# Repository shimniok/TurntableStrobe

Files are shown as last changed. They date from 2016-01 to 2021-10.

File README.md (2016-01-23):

# TurntableStrobe

Check your turntable's speed with TurntableStrobe, a highly accurate, tiny, low-cost, handheld turntable strobe. Or retrofit your turntable with the permanent-mount version.

With a crystal rated ±0.003% accuracy at 25°C, it is far more accurate than a mains frequency strobe on most turntables.

For sale on [Tindie](https://www.tindie.com/products/bot_thoughts/pocket-turntable-strobe/)

[Documentation](https://github.com/shimniok/TurntableStrobe/tree/master/documentation/)

## Features

* Crystal rated at ±0.003% accuracy at 25°C
* Use these free strobe discs: 60HzStrobeDisc.pdf or 50HzStrobeDisc.pdf
* Tiny CR1225 battery, included
* 1" long (not including the LED) x 3/4" wide
* Tactile on switch
* Handheld or Permanent mount

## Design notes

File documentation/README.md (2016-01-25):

# TurntableStrobe User Manual
Use TurntableStrobe, a highly accurate, tiny, hand held LED strobe, to check the pitch calibration of your turntable.

## Why Calibrate?
To ensure your records play back at the correct pitch (speed), you need to calibrate your deck using a turntable strobe. For the highest accuracy, TurntableStrobe uses a quartz crystal rated ±0.003% accuracy at 25°C, more than accurate enough to ensure a precise calibration.

Though many turntables have built-in strobes, they run off of the mains frequency which [varies over time](http://dabbledoo.weebly.com/mains-frequency.html). And, many turntables have no strobe. In either case, TurntableStrobe provides a quick and easy, but highly accurate, calibration reference at low cost.

## Getting Started
* Remove TurntableStrobe and the CR1225 battery from the anti-static bag
* Remove the CR1225 battery from its bubble
* Match the ```+``` symbol on the battery and battery holder
* Insert the battery with the ```+``` symbols facing up.
* Just press the button on top to activate the strobe.

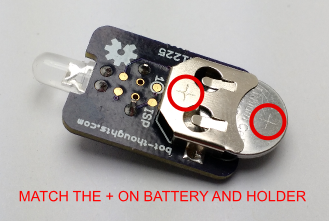
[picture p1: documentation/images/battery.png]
battery


## How to Calibrate Your Turntable
If your turntable's platter has timing marks (pictured below) skip to *Checking Calibration*. Otherwise, you can print a strobe disc as explained below.

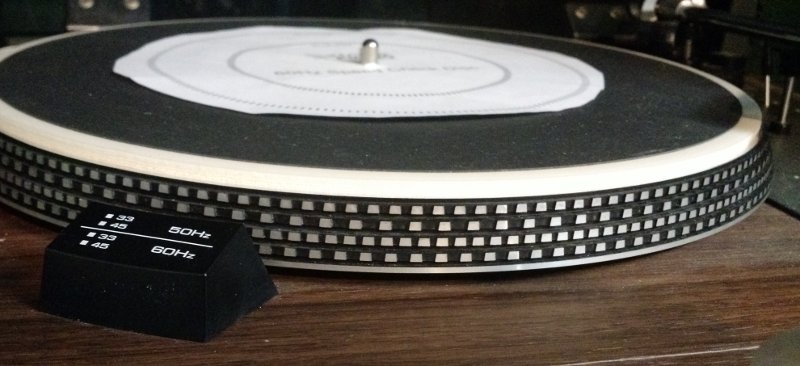
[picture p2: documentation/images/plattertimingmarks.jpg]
timing marks
  
*My Realistic Lab-400 has 50Hz and 60Hz timing marks. Strobe disc also pictured.*

1. Download one of these free turntable strobe discs on your printer:
  * [60Hz.pdf](http://www.extremephono.com/ftp/60Hz.PDF) for 60Hz TurntableStrobe
  * [50Hz.pdf](http://www.extremephono.com/ftp/50Hz.PDF) for 50Hz TurntableStrobe
* Cut out the disc and cut out a hole for the turntable spindle.
* Remove any records from the turntable
* Place the strobe disc on the turntable

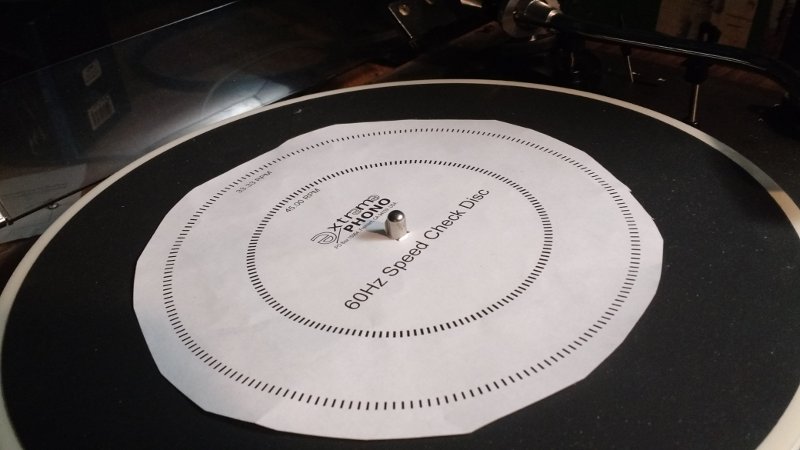
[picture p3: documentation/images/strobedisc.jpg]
strobe disc


### Checking Calibration
1. Start the turntable (refer to your owner's manual if necessary)
* Select the timing marks corresponding to the current turntable speed
* Hold the TurntableStrobe at least 2" (5cm) away from the timing marks (on the platter or strobe disc, as applicable)
* Press the TurntableStrobe button to activate the light
* The timing marks should now appear distinct though possibly a little bit blurry
* If the marks appear to be moving slowly, then the speed/pitch calibration is incorrect

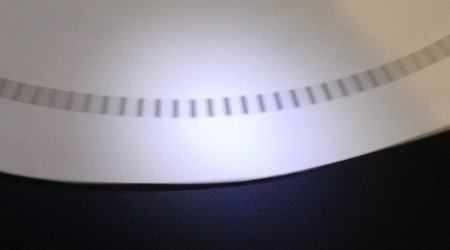
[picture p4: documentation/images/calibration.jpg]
calibration
  
*Calibration using a strobe disc*

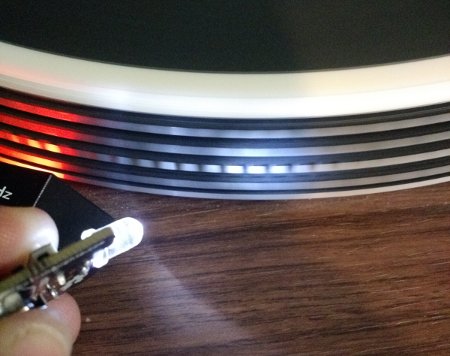
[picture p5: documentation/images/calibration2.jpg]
calibration2
  
*Calibration using platter timing marks*

If your turntable has an external pitch or speed adjustment knob, you can now adjust the speed of your deck.

### Adjusting Pitch
Some turntables have separate speed / pitch knobs for 45 rpm and 33-1/3 rpm, while others only have a single pitch knob.

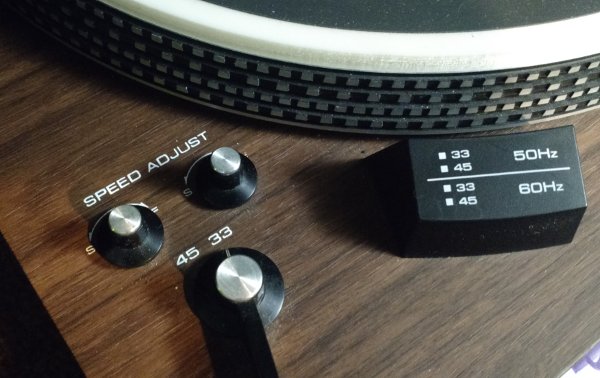
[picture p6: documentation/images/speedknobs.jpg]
LAB-400 pitch
  
*My LAB-400 has independent adjustments for 45 RPM and 33-1/3 RPM.*

1. Find the pitch knob corresponding to the current speed of the turntable.
* Adjust the pitch knob very slowly until the timing marks appear to be stationary
* You may find the marks will slowly oscillate forward and backward.
  * This variation in pitch is normal and is called *wow*.
  * Typically, better turntables have lower variation in pitch.
* To calibrate for an *average* speed, ensure the timing marks appear to move forward and backward by the same amount; that is, they remain stationary *on average*.
* It may not be possible to get it perfect. Just do your best.

## Troubleshooting

### Timing marks are an indistinct blur

| Cause | Solution |
| ----- | --- |
| Mismatch between timing marks and strobe | Make sure the platter timing marks (or strobe disc) match the frequency of your turntable strobe. |
| 45 RPM speed selected but 33-1/3 timing marks are illuminated, or vice versa | Strobe discs and turntable platters use two sets of timing marks, one for each speed. Illuminate the marks corresponding to the speed selection of your turntable. |
| Problem with turntable speed | You could try replacing the belt (if applicable), or have the turntable checked and serviced if necessary. There could be a problem with the motor, the speed controller, or something else I haven't thought of. |

### Timing difficult to make perfectly stationary

| Cause | Solution |
| ----- | --- |
| Speed/Pitch potentiometer is dirty | Clean potentiometer with Deoxit and lubricate with FaderLube or equivalent |
| Turntable wow | Lower end turntables may have a fair bit of wow. As long as you can't hear pitch variation when playing back long, sustained notes, you can ignore the wow and do your best to adjust pitch. If wow sounds excessive, you can try cleaning and lubricating the pitch potenitometer as above, replacing the belt if applicable, and/or having the turntable checked and serviced. |

### Strobe light is very dim or strobe does not light up at all

| Cause | Solution |
| ----- | --- |
| Battery is low | Change battery |

If you are still having problems, please [contact me on Tindie](https://www.tindie.com/stores/bot_thoughts/) and I'll do my best to help you out.

## Accuracy
The quartz crystals selected for use on the Turntable strobe modules have a frequency tolerance of ±30 ppm at 25 ºC (±0.003%). Temperature stability is ±30 ppm over (-20ºC - +70ºC) but of course we can expect a much narrower tolerance for normal indoor temperatures.

I measure the frequency of every single TurntableStrobe before selling it. So far. frequencies range between -0.0015% to -0.0035% of the target frequency. Testing is conducted in my basement at around 20-25°C using a Saleae Logic analyzer with 42ns accuracy.

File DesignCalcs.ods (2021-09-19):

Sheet: OperArea
Safe operating area (voltage vs frequency) |  |  |  |  | CR1225 Discharge Curves
ATtiny25SSU from datasheet
 |  |  | Linear interpolation
MHz | Max Voltage |  | m | b
10 | 2.7 | See Note | 0.18 | 0.9
11 | 2.88
12 | 3.06 | See Note
13 | 3.24
14 | 3.42
15 | 3.6
16 | 3.78
17 | 3.96
18 | 4.14
19 | 4.32
20 | 4.5
 | Note: the turntable strobe runs off a “3V” CR1225, with discharge curve running down to around 2.5V at end of life. Safe operating area for ATtiny25SSU is only 2.7V minimum. ATtiny25V can run down to 1.8V. However, expected use of the strobe will be on the order of minutes per year, so with even a 100 hour life, the battery should last for years. However, running the board at full 12MHz means potential problems in a shorter timespan, unfortunately. :( By running it at DIV8 clock, hopefully that resolves the problem.
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

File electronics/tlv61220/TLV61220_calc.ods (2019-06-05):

VFB | 0.5
R1 | 1.00E+06
R2 | 1.50E+05
VOUT | VR2 (kohm)
2.5 | 250,000 | 100000
2.7 | 227,273
2.8 | 217,391
2.9 | 208,333
3.0 | 200,000
3.1 | 192,308
3.2 | 185,185
3.3 | 178,571
3.5 | 166,667 | 16667

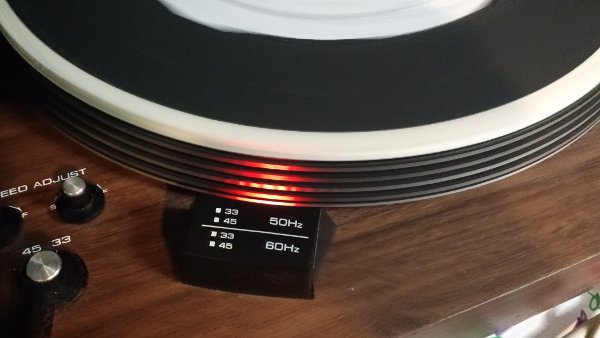
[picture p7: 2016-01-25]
documentation/images/builtinstrobe.jpg

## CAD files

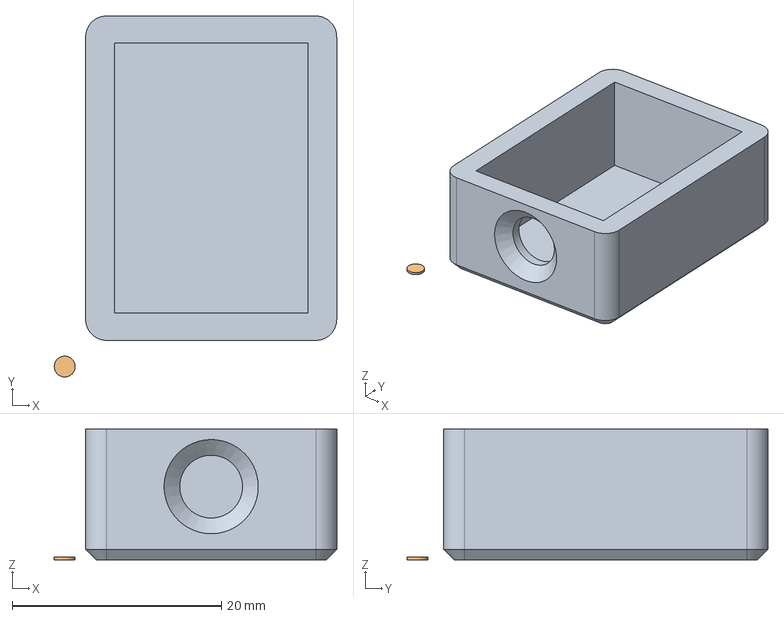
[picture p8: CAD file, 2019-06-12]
enclosure/ttstrobe_body.fcstd
27.0 x 34.5 x 12.5 mm

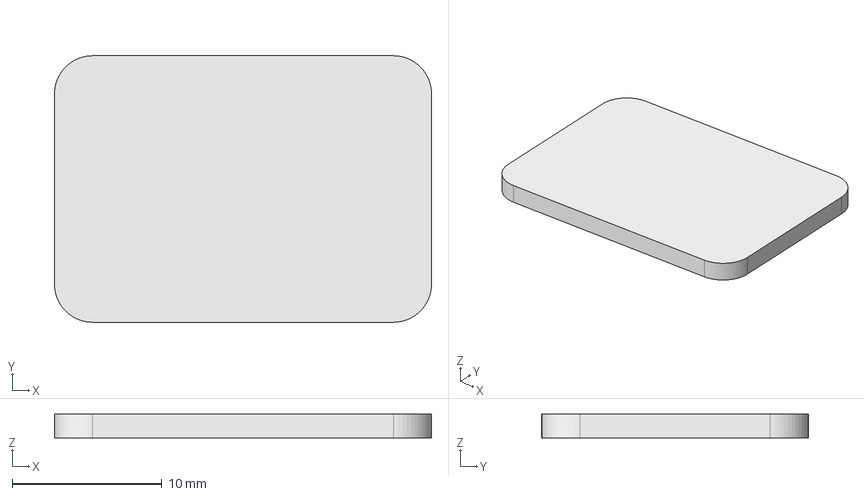
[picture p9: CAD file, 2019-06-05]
TTStrobe.fcstd
25.1 x 17.8 x 1.60 mm

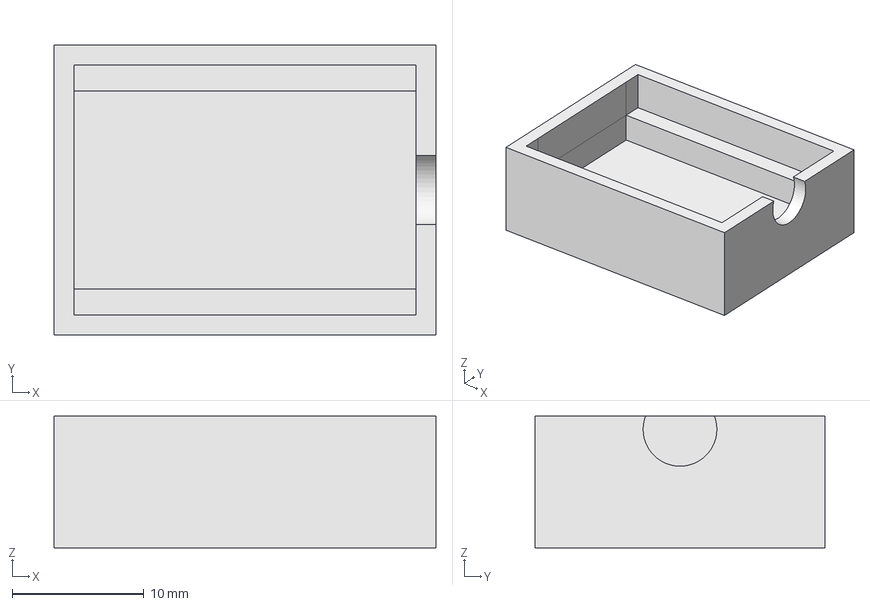
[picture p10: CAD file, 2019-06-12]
enclosure/ttstrobe.fcstd
29.0 x 22.0 x 10.0 mm

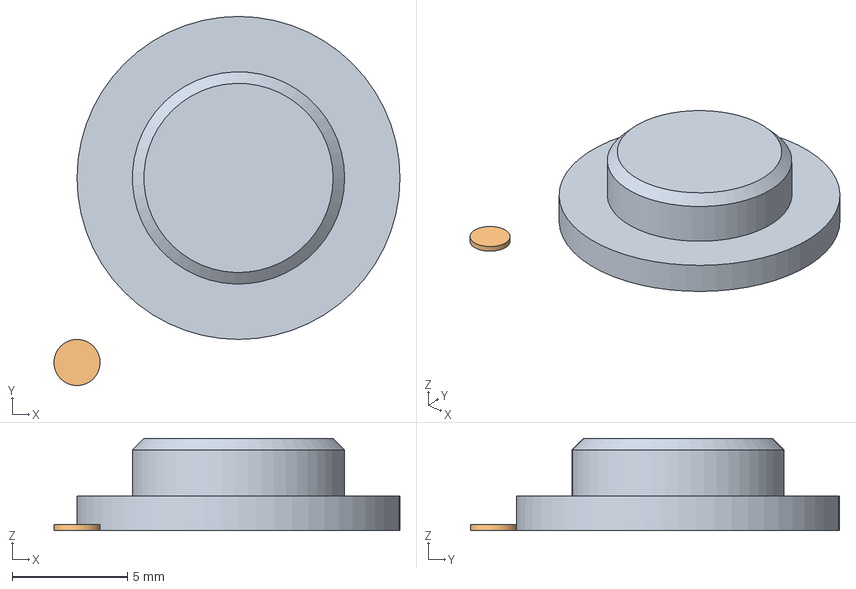
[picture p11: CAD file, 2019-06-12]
enclosure/ttstrobe_button.fcstd
15.0 x 16.0 x 4.00 mm

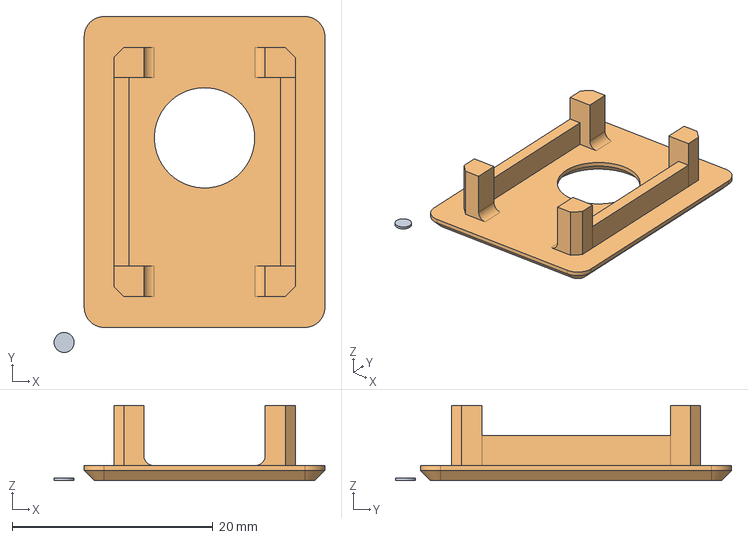
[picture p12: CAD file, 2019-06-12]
enclosure/ttstrobe_top.fcstd
27.0 x 33.5 x 7.50 mm

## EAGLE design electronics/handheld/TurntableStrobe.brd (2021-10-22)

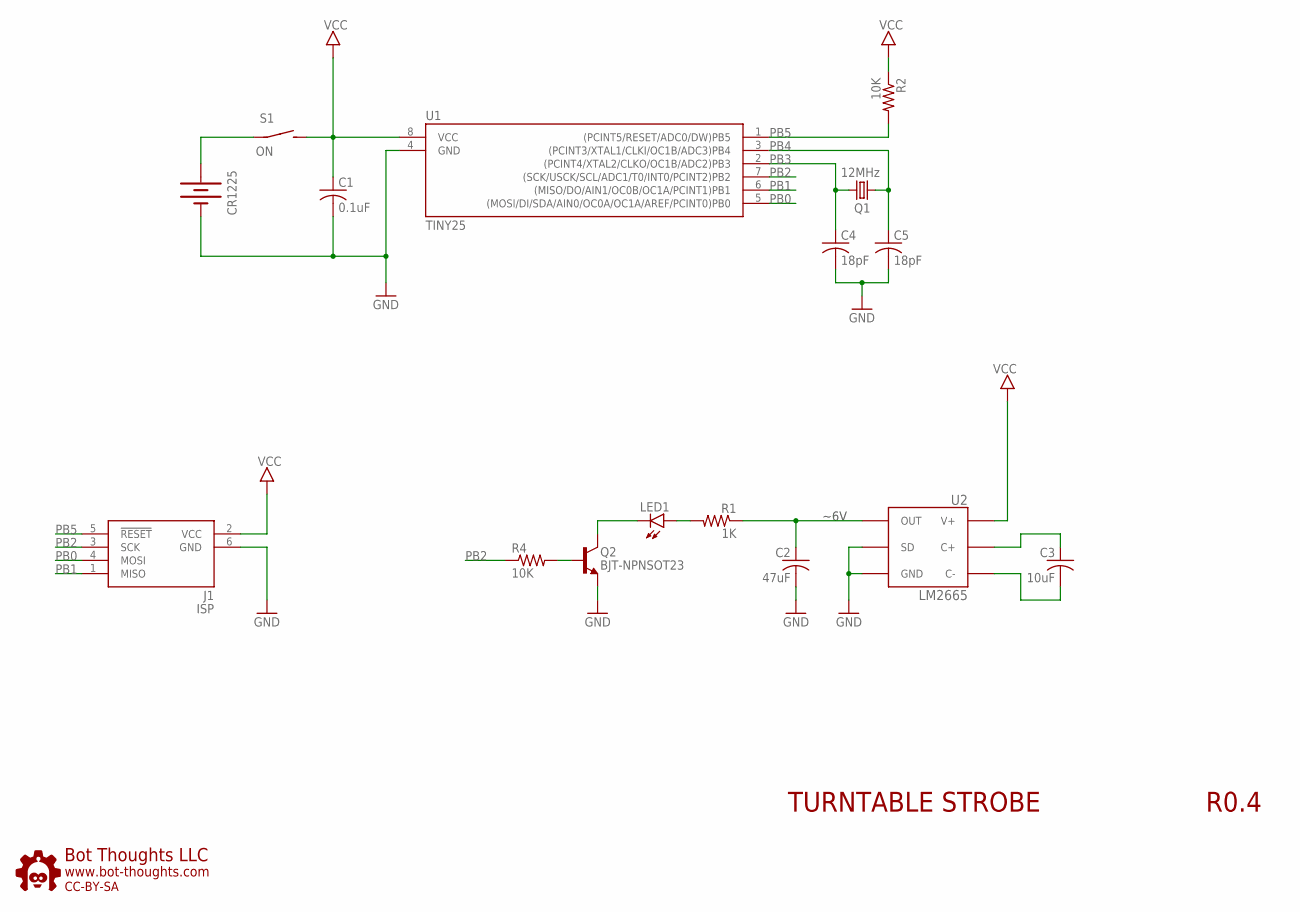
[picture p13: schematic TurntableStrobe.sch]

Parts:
C1: 0.1uF; C0603
C2: 47uF; C0603
C3: 10uF; C0603
C4, C5: 18pF; C0603
CR1225: BATTERY12PTH; BATTCON_12MM_PTH
J1: ISP; 2X3_TP
LED1: LED5MMRA
Q1: 12MHz; NDK_2PAD_5X3
Q2: BJT-NPNSOT23; SOT-23
R1: 1K; R0603
R2, R4: 10K; R0603
S1: ON; 6MMTACTILE_RECT
U1: TINY25; SOIC8N
U2: LM2665; SOT23-6
U$5: BTLOGO-LOGO-SM; BTLOGOS

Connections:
GND: C1.2, C2.2, C4.2, C5.2, CR1225.GND (-), J1.6 (GND), Q2.2 (E), U1.4 (GND), U2.2 (GND), U2.4 (SD)
unnamed: Q2.3 (B), R4.2
unnamed: C3.1, U2.6 (C+)
unnamed: LED1.A, R1.2
unnamed: C3.2, U2.3 (C-)
unnamed: LED1.C, Q2.1 (C)
PB0: J1.4 (MOSI), U1.5 ((MOSI/DI/SDA/AIN0/OC0A/OC1A/AREF/PCINT0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)
PB1: J1.1 (MISO), U1.6 ((MISO/DO/AIN1/OC0B/OC1A/PCINT1)PB1)
PB2: J1.3 (SCK), R4.1, U1.7 ((SCK/USCK/SCL/ADC1/T0/INT0/PCINT2)PB2)
PB3: C4.1, Q1.P$2 (2), U1.2 ((PCINT4/XTAL2/CLKO/OC1B/ADC2)PB3)
PB4: C5.1, Q1.P$1 (1), U1.3 ((PCINT3/XTAL1/CLKI/OC1B/ADC3)PB4)
PB5: J1.5 (!RESET), R2.2, U1.1 ((PCINT5/RESET/ADC0/DW)PB5)
VBAT: CR1225.VCC@1 (+), S1.P$1
VCC: C1.1, J1.2 (VCC), R2.1, S1.P$2 (S), U1.8 (VCC), U2.1 (V+)
VHI: C2.1, R1.1, U2.5 (OUT)

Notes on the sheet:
~6V
TURNTABLE STROBE
R0.4

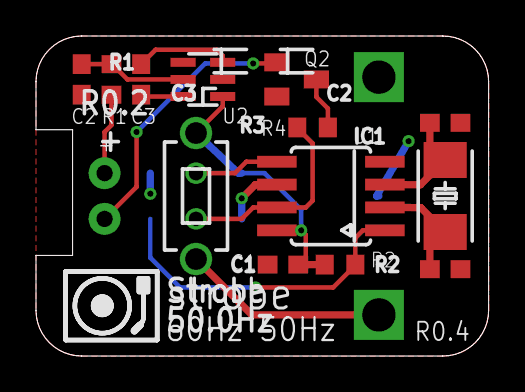
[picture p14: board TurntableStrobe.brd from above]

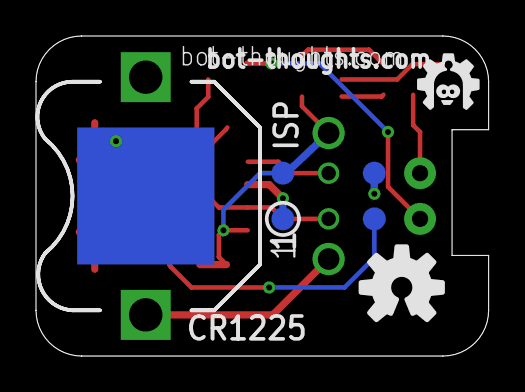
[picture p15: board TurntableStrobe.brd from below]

Board: 2 copper layers, 25.1 x 17.8 mm, 17 parts (3 on the bottom side), 15 nets.

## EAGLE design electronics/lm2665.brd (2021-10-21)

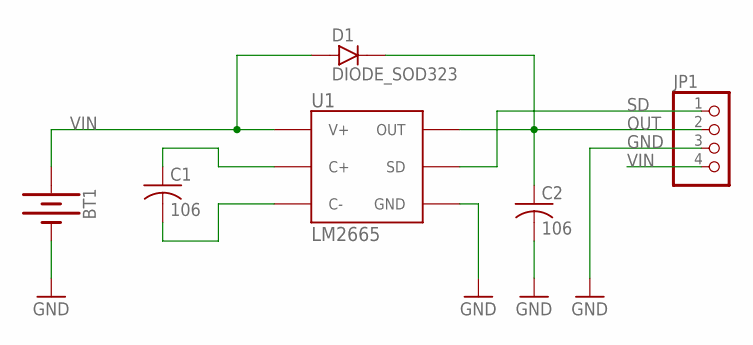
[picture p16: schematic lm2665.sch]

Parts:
BT1: BATTERY-12MM_PTH; BATTCON_12MM_PTH
C1, C2: 106; 1206
D1: DIODE_SOD323; SOD-323
JP1: PINHD-1X04_2.54-S; 1X04-S
U1: LM2665; SOT23-6

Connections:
GND: BT1.GND (-), C2.2 (-), JP1.3, U1.2 (GND)
unnamed: C1.1 (+), U1.6 (C+)
unnamed: C1.2 (-), U1.3 (C-)
OUT: C2.1 (+), D1.C, JP1.2, U1.5 (OUT)
SD: JP1.1, U1.4 (SD)
VIN: BT1.VCC@1 (+), D1.A, JP1.4, U1.1 (V+)

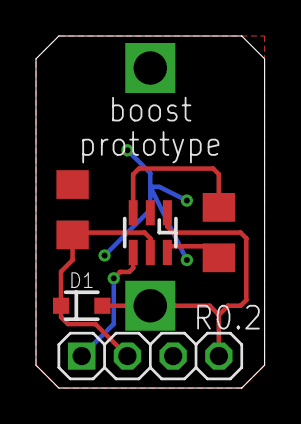
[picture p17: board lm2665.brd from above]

Board: 2 copper layers, 12.7 x 19.6 mm, 6 parts (1 on the bottom side), 6 nets.

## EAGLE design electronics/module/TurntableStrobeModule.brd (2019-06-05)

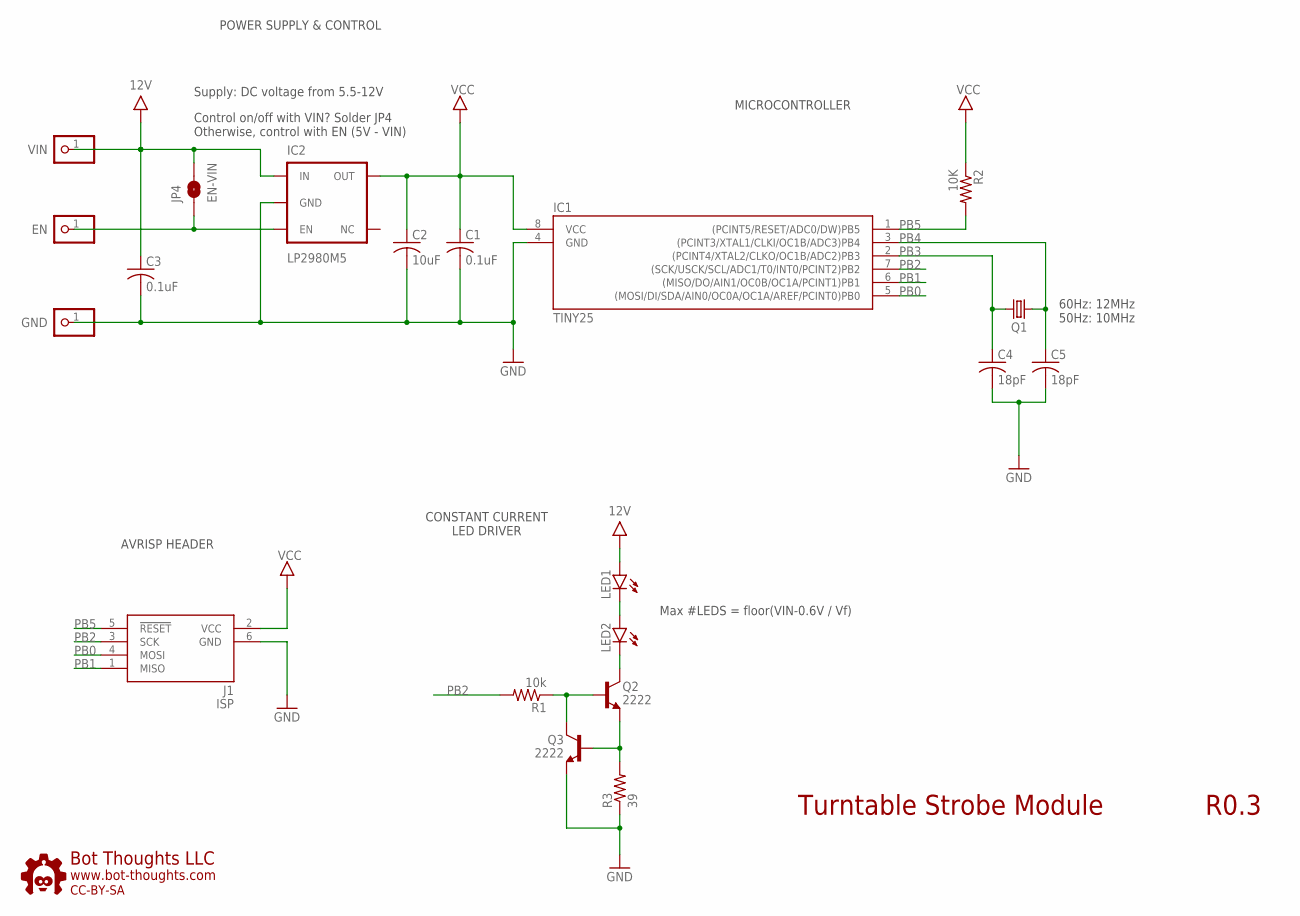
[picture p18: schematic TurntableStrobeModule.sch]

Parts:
C1, C3: 0.1uF; 0603
C2: 10uF; 1206
C4, C5: 18pF; 0603
IC1: TINY25; SOIC8N
IC2: LP2980M5; SOT23-5
J1: ISP; CON6P2R
JP1: EN; 1X01-S
JP2: VIN; 1X01-S
JP3: GND; 1X01-S
JP4: EN-VIN; SMT-JUMPER_2_NO_SILK
LED1, LED2: LED5MMRA
Q1: CRYSTALNDK5X3; NDK_2PAD_5X3
Q2, Q3: 2222; SOT-23
R1: 10k; 0603
R2: 10K; 0603
R3: 39; 0603
U$6: BTLOGO-LOGO-MD; BTLOGOM

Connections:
9V: C3.1 (+), IC2.1 (IN), JP2.1, JP4.2, LED1.A
GND: C1.2 (-), C2.2 (-), C3.2 (-), C4.2 (-), C5.2 (-), IC1.4 (GND), IC2.2 (GND), J1.6 (GND), JP3.1, Q3.2 (E), R3.1
unnamed: Q2.3 (B), Q3.1 (C), R1.1
unnamed: LED1.C, LED2.A
unnamed: LED2.C, Q2.1 (C)
unnamed: Q2.2 (E), Q3.3 (B), R3.2
unnamed: IC2.3 (EN), JP1.1, JP4.1
PB0: IC1.5 ((MOSI/DI/SDA/AIN0/OC0A/OC1A/AREF/PCINT0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), J1.4 (MOSI)
PB1: IC1.6 ((MISO/DO/AIN1/OC0B/OC1A/PCINT1)PB1), J1.1 (MISO)
PB2: IC1.7 ((SCK/USCK/SCL/ADC1/T0/INT0/PCINT2)PB2), J1.3 (SCK), R1.2
PB3: C4.1 (+), IC1.2 ((PCINT4/XTAL2/CLKO/OC1B/ADC2)PB3), Q1.P$2 (2)
PB4: C5.1 (+), IC1.3 ((PCINT3/XTAL1/CLKI/OC1B/ADC3)PB4), Q1.P$1 (1)
PB5: IC1.1 ((PCINT5/RESET/ADC0/DW)PB5), J1.5 (!RESET), R2.2
VCC: C1.1 (+), C2.1 (+), IC1.8 (VCC), IC2.5 (OUT), J1.2 (VCC), R2.1

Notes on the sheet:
Turntable Strobe Module
R0.3
60Hz: 12MHz 50Hz: 10MHz
Control on/off with VIN? Solder JP4 Otherwise, control with EN (5V - VIN)
Supply: DC voltage from 5.5-12V
Max #LEDS = floor(VIN-0.6V / Vf)
CONSTANT CURRENT LED DRIVER
AVRISP HEADER
POWER SUPPLY & CONTROL
MICROCONTROLLER

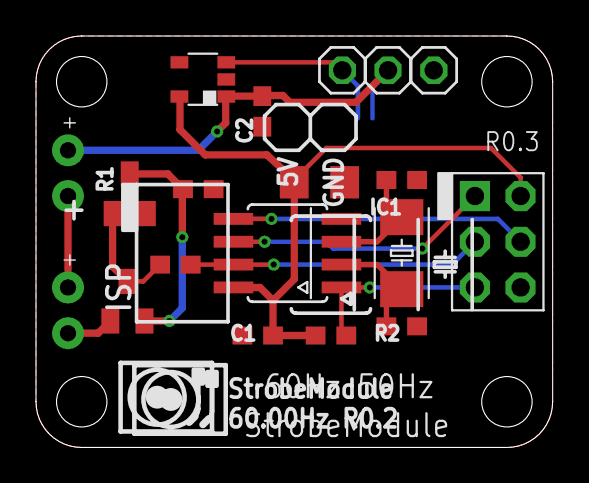
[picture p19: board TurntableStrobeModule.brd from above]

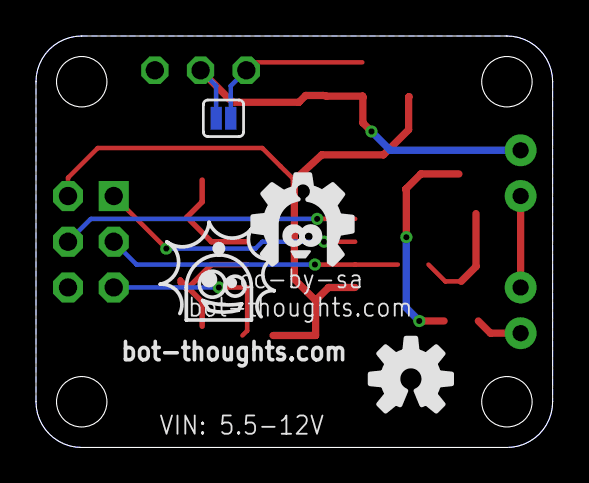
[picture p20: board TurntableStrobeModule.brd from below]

Board: 2 copper layers, 28.7 x 22.9 mm, 21 parts (2 on the bottom side), 14 nets.

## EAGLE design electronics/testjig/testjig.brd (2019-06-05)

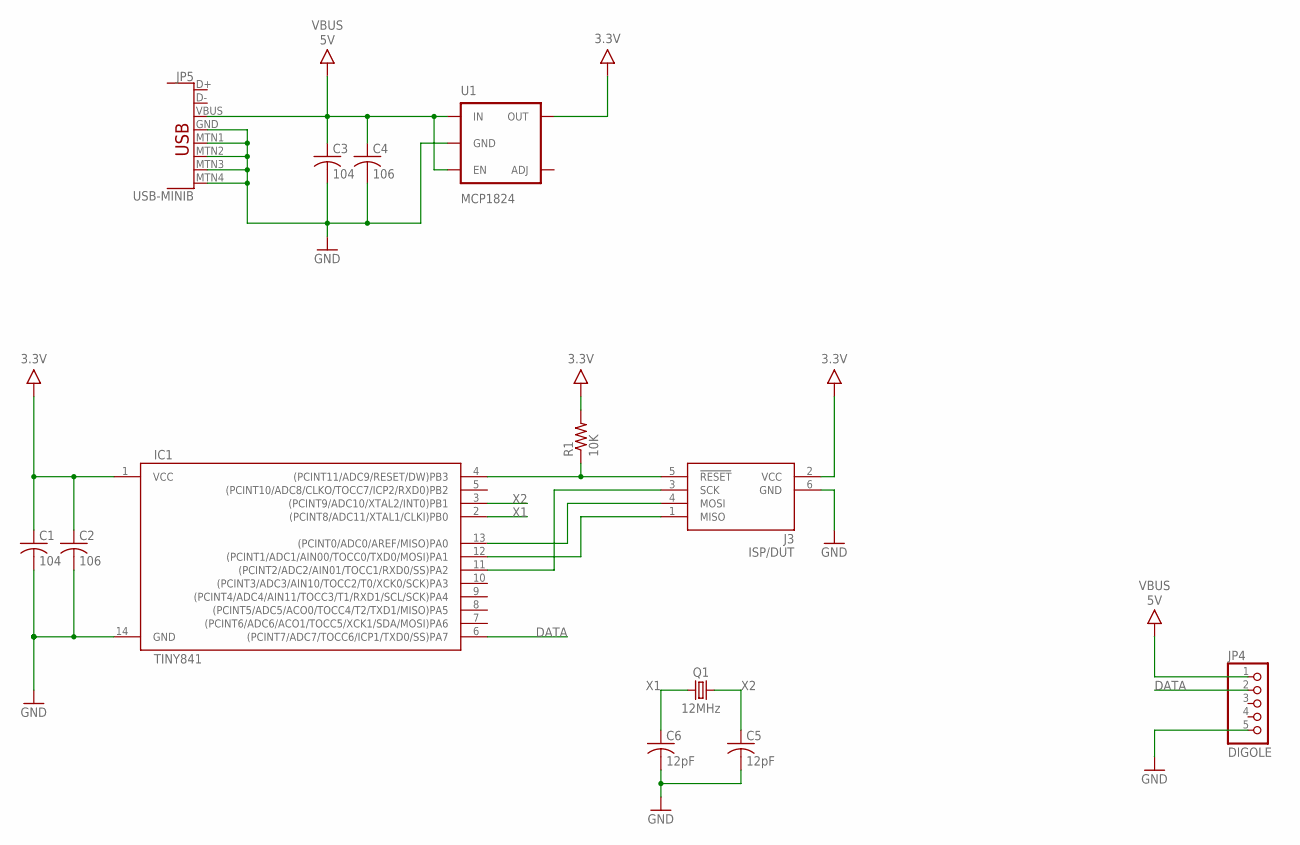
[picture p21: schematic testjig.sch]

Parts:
C1, C3: 104; 0603
C2, C4: 106; 0603
C5, C6: 12pF; 0603
IC1: TINY841; SOIC14N
J3: ISP/DUT; CON6P2R
JP4: DIGOLE; 1X05-S
JP5: USB-MINIB
Q1: 12MHz; NDK_2PAD_5X3
R1: 10K; 0603
U1: MCP1824; SOT23-5

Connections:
3.3V: C1.1 (+), C2.1 (+), IC1.1 (VCC), J3.2 (VCC), R1.2, U1.5 (OUT)
DATA: IC1.6 ((PCINT7/ADC7/TOCC6/ICP1/TXD0/SS)PA7), JP4.2
GND: C1.2 (-), C2.2 (-), C3.2 (-), C4.2 (-), C5.2 (-), C6.2 (-), IC1.14 (GND), J3.6 (GND), JP4.5, JP5.GND, JP5.MTN1 (SHIELD1), JP5.MTN2 (SHIELD2), JP5.MTN3 (SHIELD3), JP5.MTN4 (SHIELD4), U1.2 (GND)
PA0: IC1.13 ((PCINT0/ADC0/AREF/MISO)PA0), J3.4 (MOSI)
PA1: IC1.12 ((PCINT1/ADC1/AIN00/TOCC0/TXD0/MOSI)PA1), J3.1 (MISO)
PA2: IC1.11 ((PCINT2/ADC2/AIN01/TOCC1/RXD0/SS)PA2), J3.3 (SCK)
RESET: IC1.4 ((PCINT11/ADC9/RESET/DW)PB3), J3.5 (!RESET), R1.1
VBUS: C3.1 (+), C4.1 (+), JP4.1, JP5.VBUS, U1.1 (IN), U1.3 (EN)
X1: C6.1 (+), IC1.2 ((PCINT8/ADC11/XTAL1/CLKI)PB0), Q1.P$1 (1)
X2: C5.1 (+), IC1.3 ((PCINT9/ADC10/XTAL2/INT0)PB1), Q1.P$2 (2)

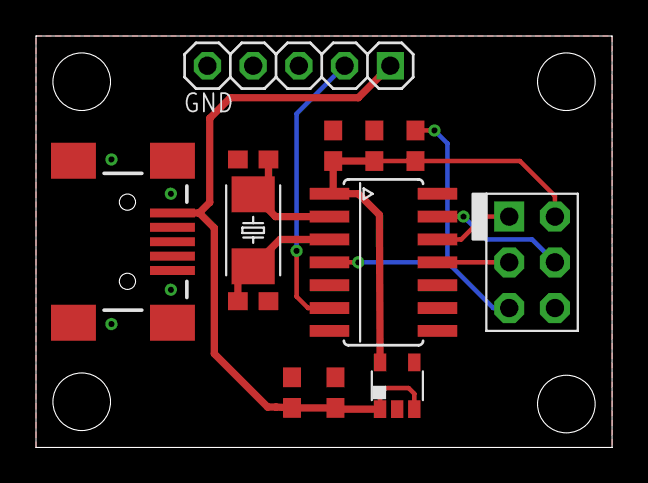
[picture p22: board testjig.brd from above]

Board: 2 copper layers, 32.0 x 22.9 mm, 13 parts (0 on the bottom side), 10 nets.

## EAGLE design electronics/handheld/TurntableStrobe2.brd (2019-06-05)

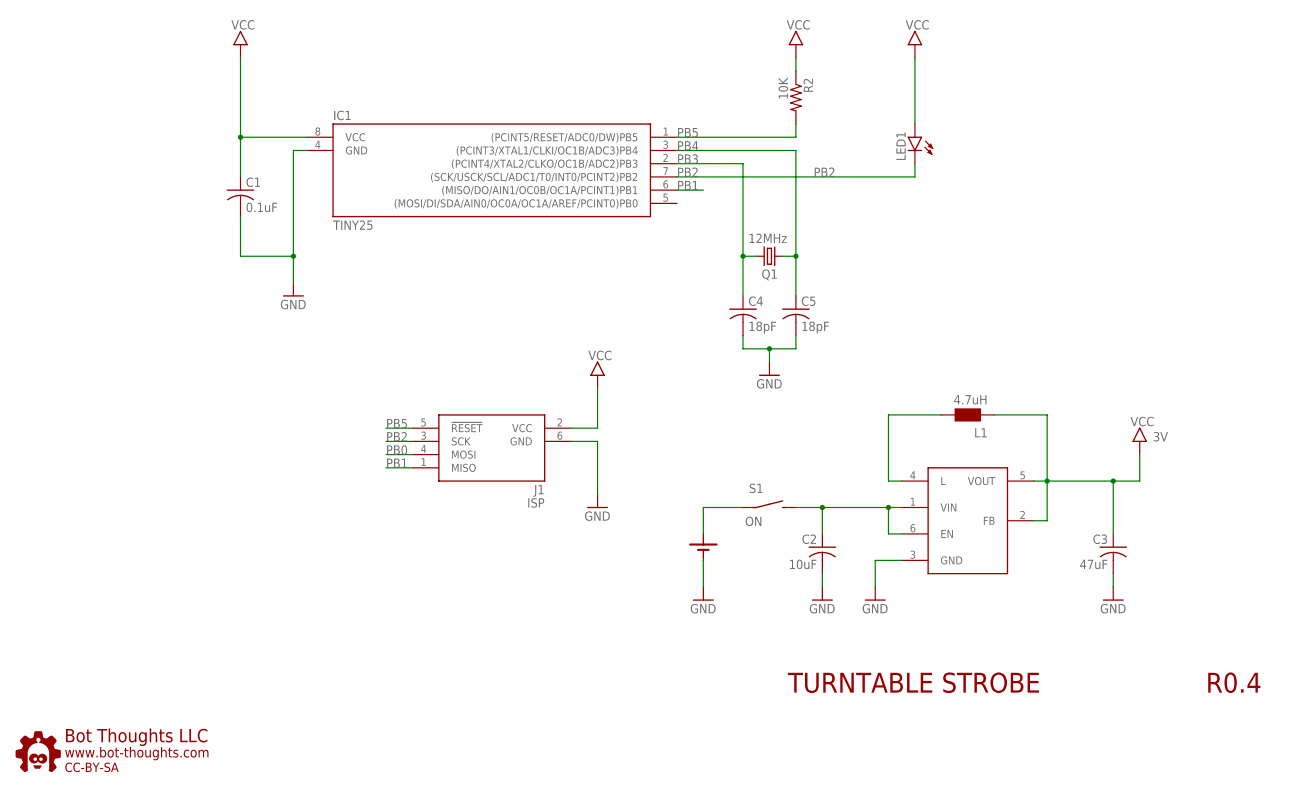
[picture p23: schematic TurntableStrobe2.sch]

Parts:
C1: 0.1uF; C0603
C2: 10uF; C0603
C3: 47uF; 1206
C4, C5: 18pF; C0603
CR1225: LR44_PTH; LR44
IC1: TINY25; SOIC8N
J1: ISP; 2X3_TP
L1: 4.7uH; 0805
LED1: LED5MMRA
Q1: 12MHz; NDK_2PAD_5X3
R2: 10K; R0603
S1: ON; 6MMTACTILE_RECT
U1: TLV61224; SC70-6
U$5: BTLOGO-LOGO-MD; BTLOGOM

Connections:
GND: C1.2, C2.2, C3.2 (-), C4.2, C5.2, CR1225.GND (-), IC1.4 (GND), J1.6 (GND), U1.3 (GND)
unnamed: L1.2, U1.4 (L)
PB0: J1.4 (MOSI)
PB1: IC1.6 ((MISO/DO/AIN1/OC0B/OC1A/PCINT1)PB1), J1.1 (MISO)
PB2: IC1.7 ((SCK/USCK/SCL/ADC1/T0/INT0/PCINT2)PB2), J1.3 (SCK), LED1.C
PB3: C4.1, IC1.2 ((PCINT4/XTAL2/CLKO/OC1B/ADC2)PB3), Q1.P$2 (2)
PB4: C5.1, IC1.3 ((PCINT3/XTAL1/CLKI/OC1B/ADC3)PB4), Q1.P$1 (1)
PB5: IC1.1 ((PCINT5/RESET/ADC0/DW)PB5), J1.5 (!RESET), R2.2
VBAT: CR1225.+1 (+), CR1225.+2 (+), S1.P$1
VCC: C1.1, C3.1 (+), IC1.8 (VCC), J1.2 (VCC), L1.1, LED1.A, R2.1, U1.2 (FB), U1.5 (VOUT)
VIN: C2.1, S1.P$2 (S), U1.1 (VIN), U1.6 (EN)

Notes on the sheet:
TURNTABLE STROBE
R0.4

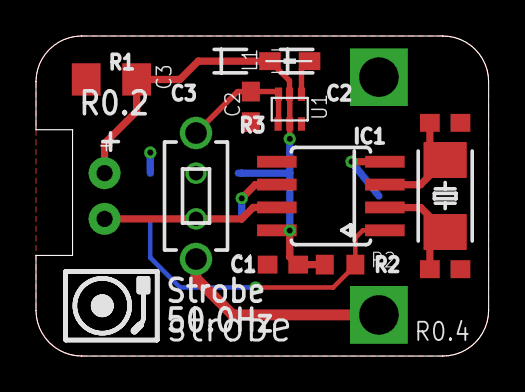
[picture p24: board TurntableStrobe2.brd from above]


Board: 2 copper layers, 25.1 x 17.8 mm, 15 parts (3 on the bottom side), 10 nets.

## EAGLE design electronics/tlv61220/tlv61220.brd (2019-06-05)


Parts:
C1, C2: 106; 1206
JP1: PINHD-1X03_2.54-S; 1X03-S
L1: 4.7uH; WE-KI_0805_B
R1: 1M; 0603
R2: 150K; 0603
U1: TLV61220; SOT23-6
U$1: LR44_PTH; LR44
VR1: 100K; POT_0.2X0.25

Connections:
EN: JP1.2, U1.3 (EN)
GND: C1.2 (-), C2.2 (-), JP1.3, U1.2 (GND), U$1.GND (-), VR1.A
unnamed: C1.1 (+), U1.6 (VBAT), U$1.+1 (+), U$1.+2 (+)
unnamed: R1.1, R2.2, U1.4 (FB)
unnamed: R2.1, VR1.W (WIPER)
SW: L1.2 (1), U1.1 (SW)
VOUT: C2.1 (+), JP1.1, L1.1 (2), R1.2, U1.5 (VOUT)

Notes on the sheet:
Adjustable 2.5-3.5V. See datasheet


Board: 2 copper layers, 17.8 x 26.4 mm, 9 parts (0 on the bottom side), 7 nets.

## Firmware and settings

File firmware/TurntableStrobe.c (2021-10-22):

#include <avr/io.h>
#include <avr/interrupt.h>
#include <util/delay.h>

/**
 * Turntable Strobe driver for ATtiny25 family
 *
 * @author: Michael Shimniok - www.bot-thoughts.com
 * @created: 3/11/2014
 * @description: Firmware for TurntableStrobe used to calibrate
 * turntable speed. Most turntables use some form of incandescent bulb
 * running off mains, which means they light up twice per cycle. To
 * emulate this behavior, the firmware pulses an LED at 120Hz (60Hz
 * mains) or 100Hz (50Hz mains). It also runs a simple Dickson charge
 * pump to "double" voltage for the LED strobe.
 *
 * For the LED, TIMER1 is used with overflow interrupt to increment a
 * counter variable for precise timing. Another variable controls the
 * duty cycle.
 *
 * While I realize there are other ways to do all this (such as running
 * the charge pump off OC1A) this is what I chose for now. No need to
 * overthink things, right? :)
 *
 * For more design details see DesignCalcs.ods.
 */

/**
 * Assumes CKDIV8 is set and that we're using a 12MHz xtal to get
 * 120Hz strobe. All we have to do to get 100Hz is to change to a
 * 10MHz xtal--no change to firmware (which is significantly more
 * convenient when you're trying to make an sell a bunch of these)
 */

// We're expecting certain macros defined externally
#if F_STROBE == 50
#  if F_XTAL == 10
#    define PERIOD 125
#    define ONTIME 40
#    define MATCH 25
#  elif F_XTAL == 12
#    define PERIOD 150
#    define ONTIME 48
#    define MATCH 25
#  elif F_XTAL == 147
#    define PERIOD 192
#    define ONTIME 61
#    define MATCH 24
#  else
#    error F_XTAL must be 10, 12, or 147 for 50Hz
#  endif
#elif F_STROBE == 60
#  if F_XTAL == 12
#    define PERIOD 125
#    define ONTIME 40
#    define MATCH 25
#  elif F_XTAL == 147
#    define PERIOD 160
#    define ONTIME 51
#    define MATCH 24
#  else
#    error F_XTAL must be 12 or 147 for 60Hz
#  endif
#else
#  error F_STROBE must be 50 or 60
#endif

/**
 * I could put one of these on OC1A ... but it's not like the
 * microcontroller has much else to do.
 */
#define LED  PB2
#define PUMP PB0

/**
 * The LED cathode is pulled to ground with an NPN BJT
 * Base is connected to the LED GPIO pin, thus:
 *   GPIO high --> LED on
 *   GPIO low  --> LED off
 */
inline void led(const uint8_t on) {
	if (on) {
		PORTB |= (1<<LED);
	} else {
		PORTB &= ~(1<<LED);
	}
}

int main() {
	DDRB |= (1<<LED);  // Make GPIO an output
	led(0);            // Turn off LED to start with

	TCCR1 |= (1<<PWM1A)|    			// PWM using OCR1A to count and OCR1C to match;
					 (1<<CTC1)|				    // Clear timer on compare match;
			     (1<<CS11)|(1<<CS10);	// Timer prescaler, see DesignCalcs.ods, TimerCalc tab
	OCR1C = MATCH-1;				      // To get N counts, set OCR1C to N-1
	TIMSK |= (1<<TOIE1);			    // Enable interrupt on timer overflow
	sei();

	while (1) {
		_delay_ms(1); // nothing to do here; blinking is timer interrupt-driven
	}
}

/**
 * This ISR handles the TIMER1 overflow, which is set to a fairly high
 * Frequency to allow precise software timing of the actual on and off
 * times of the LED (controlled by PERIOD and ONTIME).
 *
 * While we're at it, we go ahead and pulse the charge pump, too.
 */
ISR(TIM1_OVF_vect) {
	static uint8_t count = 0;

	count++;
	if (count >= PERIOD) count = 0;

	led(count < ONTIME);
}

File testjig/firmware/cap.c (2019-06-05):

// Capture module implements capture timing of waveform
#include <avr/io.h>
#include <avr/interrupt.h>
#include "cap.h"

#define QMASK 0x1f
cap_sample_t sample[QMASK+1];
volatile uint8_t pause = 0;
uint8_t in = 0;
uint8_t out = 0;
#define inc(x) (((x)+1) & QMASK)

void cap_enq(unsigned long start, unsigned long mid, unsigned long stop) {
	uint8_t i = inc(in);
	if (i != out) {
		sample[i].start = start;
		sample[i].mid = mid;
		sample[i].stop = stop;
		in = i;
	}
}

uint8_t cap_deq(long *start, long *mid, long *stop) {
	uint8_t status = 0;

	if (in != out && start && mid && stop ) {
		*start = sample[out].start;
		*mid = sample[out].mid;
		*stop = sample[out].stop;
		out = inc(out);
		status = 1;
	}

	return status;
}

void cap_init() {
	// Normal mode; clear on MAX
	//TCCR1A = 0;

	// noise cancelling, rising edge, prescaler: 8
	TCCR1B |= (1<<ICNC1)|(1<<ICES1)|(1<<CS11);

	// interrupt on input capture edge detect & output compare (timeout)
	TIMSK1 |= (1<<ICIE1);//|(1<<OCIE1A);

	//debug
	DDRA |= (1<<PA0)|(1<<PA2);
	PORTA &= ~((1<<PA0)|(1<<PA2));
}

ISR(TIMER1_CAPT_vect) {
	unsigned long icr;
	static unsigned long start_time = 0;
	static unsigned long mid_time = 0;

	uint8_t tccr;

	// immediately save capture register value
	icr = ICR1;

	// reverse the edge detect, must occur very soon after reading ICR
	tccr = TCCR1B; // save edge detect setting
	TCCR1B = tccr ^ (1<<ICES1);

	// End/Begin period if we were just looking for rising edge
	if (tccr & (1<<ICES1)) {
		PORTA |= (1<<PA2);
		cap_enq(start_time, mid_time, icr); // Save sample data

		// Start of new pulse/period
		start_time = icr;

	} else {
		mid_time = icr;		// Capture falling-edge time
		PORTA &= ~(1<<PA2);
	}

	return;
}

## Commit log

2015-03-17 updated gitignore
    [TimingCalcs.ods]
2015-03-17 updated with different numbers to support 12mhz(60hz) 10mhz(50hz) operation with identical binaries
    [TimingCalcs.ods]
2015-03-19 Reverted to original code. Fixed original makefile for much slower bitclock so I can flash these with LED installed
    [TimingCalcs.ods]
2015-03-20 Reverted to original, then hardcoded period into code so we can use 10mhz/12mhz xtals to determine frequency, tweaked isr to have count reset to 0 separately before main if-else
    [TurntableStrobe.c]
2015-03-20 updated TimingCalcs
    [TimingCalcs.ods]
2015-06-18 added safe operating area spreadsheet calcs/info
    [SafeOperatingArea.ods]
2015-06-19 Consolidated all calcs into single spreadsheet, added significant detail about safe operating area.
    [DesignCalcs.ods, SafeOperatingArea.ods, TimingCalcs.ods]
2015-07-02 Lowered frequency via CKDIV8, changed frequency to 120Hz/100Hz, moved charge pump toggle to ISR, added documentation, created function for led on/off
    [DesignCalcs.ods]
2015-11-10 slowed bitrate for programming; combined fuses and programming into single command line
2015-11-10 mods to design calculations spreadsheet
    [DesignCalcs.ods]
2016-03-07 added solder jumper for easier reprogramming. Minor silk tweaks. New logo.
    [TurntableStrobe.brd, TurntableStrobe.sch]
2016-03-07 subdirectory for ttstrobe module
    [TurntableStrobeModule.brd, TurntableStrobeModule.sch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]
2016-03-07 subdir for handheld and module
    [TurntableStrobe.brd, TurntableStrobe.sch, TurntableStrobeModule.brd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]
2016-03-08 Lastest version as ordered
    [TurntableStrobe.brd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]
2017-05-01 Created test jig
    [testjig.brd, testjig.sch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]
2017-05-17 zip of gerbers
2019-06-05 TLV61220 initial test run
    [tlv61220.brd, tlv61220.sch]
2019-06-05 updates to design calculations
    [DesignCalcs.ods]
2019-06-05 lr44, boost ttstrobe, initial.
    [TurntableStrobe2.brd, TurntableStrobe2.sch]
2019-06-05 Test jig initial(?)
    [testjig.brd, testjig.sch]
2019-06-05 added regulator onboard, changed some packages
    [TurntableStrobeModule.brd, TurntableStrobeModule.sch]
2019-06-05 enclosure, initial version
    [TTStrobe.fcstd]
2019-06-12 initial working version of enclosure
    [ttstrobe.fcstd, ttstrobe_body.fcstd, ttstrobe_button.fcstd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]
2021-09-19 updates to design calcs spreadsheet
    [DesignCalcs.ods]
2021-10-20 Prototype LM2665 charge pump
    [TurntableStrobe.brd, TurntableStrobe.sch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]
2021-10-21 index on proto3: 4796ad3 Prototype LM2665 charge pump
2021-10-21 replace charge pump with ic
    [TurntableStrobe.brd, TurntableStrobe.sch]
2021-10-21 updated sch with todo items, fixed brd silk
    [TurntableStrobe.brd, TurntableStrobe.sch]
2021-10-21 updated silkscreen
    [TurntableStrobe.brd]
2021-10-21 restored lm2665 changes to brd/sch
    [TurntableStrobe.brd, TurntableStrobe.sch]
2021-10-22 updated documentation, code for bjt driven led
2021-10-22 updated supply caps
    [TurntableStrobe.brd, TurntableStrobe.sch]

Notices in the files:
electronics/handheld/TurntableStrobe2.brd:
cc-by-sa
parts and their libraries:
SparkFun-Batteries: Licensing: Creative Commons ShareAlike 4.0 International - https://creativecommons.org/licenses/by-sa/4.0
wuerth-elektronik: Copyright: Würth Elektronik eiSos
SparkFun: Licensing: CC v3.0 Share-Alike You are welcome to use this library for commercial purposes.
